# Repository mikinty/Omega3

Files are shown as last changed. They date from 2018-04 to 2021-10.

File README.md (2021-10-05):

# Omega<sup>3</sup>

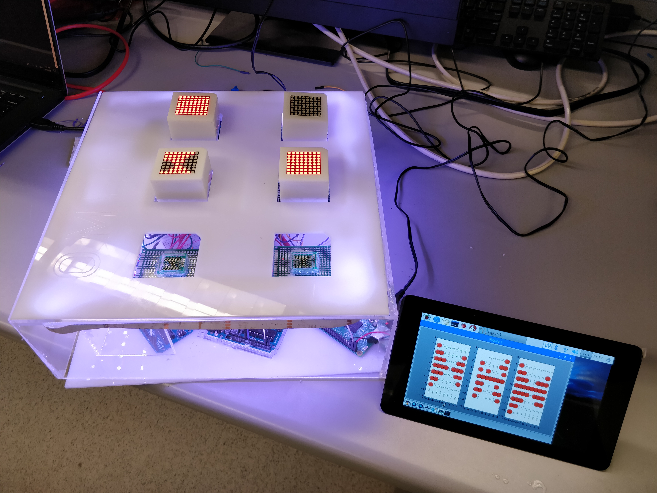
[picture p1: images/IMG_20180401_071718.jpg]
Omega3 Picture


A real-time visualization of neural networks to uncover their inner workings and help educate people about machine learning.

See the full paper at https://ieeexplore.ieee.org/document/8882046

## Directory Structure

- `CAD files/`: the CAD files used in the fabrication of Omega<sup>3</sup>.
- `images/`: pictures taken during the construction of Omega<sup>3</sup>.
- `paper/`: files used to write the paper "Real-Time Visualization of Neural Network Training to Supplement Machine Learning Education"
- `src/`: source code for the project. Includes code for the Raspberry Pi and Arduino.

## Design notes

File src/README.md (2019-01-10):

# Omega<sup>3</sup> Source Code

This directory contains the source code used to implement Omega<sup>3</sup>.
Here, we have files that test and implement the Raspberry Pi to Arduino communication interface.
The idea is that we have a Raspberry Pi that runs the neural network training code, and then sends data to the Arduino, which then displays the information on the LED matrix peripherals.

## Hardware

- Raspberry Pi 3 Model B
- Arduino Mega R2560 (can also be implemented with two Arduino UNOs)
- 8x8 LED Matrix HT16K33

## Directory Structure

- __Raspberry Pi__
  - `neuralnet.py`: the Raspberry Pi code that implements the neural network. The program takes in user input, communicates to the Arduino to display information on the LED matrices, and also plots input/output data in live-time.
  - `targetFuncs.py`: library that contains test functions to train the neural network on.
- __Arduino__
  - `testConnection`: a minimal implementation of detecting LED backpacks via hard-wired I2C addressing and displaying static information.
  - `testMatrix`: interface between the Raspberry Pi and the LED matrices. Essentially translates Rasberry Pi neural network data into images to be shown on the LED matrices.

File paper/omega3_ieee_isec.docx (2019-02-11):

# Real-Time Visualization of Neural Network Training to Supplement Machine Learning Education

Michael You and Jessica Yin

Carnegie Mellon University, myou, jessicay@andrew.cmu.edu

Abstract - In machine learning, neural networks have excelled at performing tasks at a high level with a simple and flexible implementation. Neural networks are particularly well-suited for novice programmers due to the availability of open-source libraries like TensorFlow and Caffe. However, novice programmers often neglect to learn beyond the black-box behaviors that these libraries provide. Introductory college students often lack the understanding of neural network internals, such as hidden layers and activation functions, and their interactions during training, which are crucial to efficiently solving more complex problems. Here, we present Omega³, a device that opens up the black-box of neural networks by visually representing how hidden layers behave during training in real-time. In addition, Omega³ provides an engaging tactile and visual educational experience to students, and waives the requirement for a strong programming background in order to learn about neural networks. In this paper, we will discuss the fabrication and set-up of Omega³ as well as evaluate and compare Omega³ to traditional lecture-based learning.

Index Terms – Hidden layer, modular, neural networks, visualization

Introduction

In the past decade, machine learning has emerged as one of the dominant techniques in software for building solutions in autonomous driving, natural language processing, image processing, and many other domains [1, 2, 3]. One leading technique for machine learning models is the neural network (NN), which is usually the best performing model compared to others [4, 5, 6, 7]. However, despite their success, the inner workings of NNs are seldom understood due to the sophisticated math associated with how they work [8]. As a result, people often treat NNs as black-boxes, which can lead to blindly changing parameters and features that describe the NN. As NNs become more complex, understanding how they work is vital for them to be used properly and effectively in future applications.

Currently, NN visualizations are limited. They are primarily software based, and require some degree of machine learning, data science, and/or programming experience [9, 10, 11].

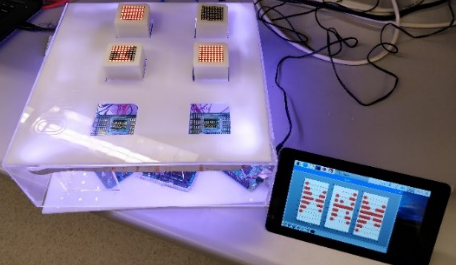
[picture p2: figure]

# Figure I

omega³ performing real-time training.

As machine learning gains popularity, an increasing number of people will need to learn about models such as neural networks. However, the programming and math can be inaccessible, out of scope, and present a high overhead to both students and teachers alike to learn.

There are numerous educational tools that target an analogous challenge with teaching children the fundamentals of programming. For example, toys such as Fisher-Price Think & Learn Code-a-pillar, littleBits, and LEGO BOOST make abstract programming concepts accessible to preschool and elementary school aged children [12, 13, 14]. These toys rely on hands-on and modular features to be engaging and effective, appealing to both visual and physical learning pathways.

TensorFlow Playground, a web-based interactive NN visualization, has been developed to address the growing need for accessible NN education. However, it still requires an extensive background in programming and math for basic use and may be less advantageous for tactile learners.

Building upon TensorFlow Playground, we present a simple, modular, physical representation of a NN that is easily accessible and requires minimal technical experience. This device, which we call Omega³, has customizable data and training settings, and displays a real-time visual of how a NN works as it runs. The user can move modular neuron blocks on the device that change the structure of the NN in real-time, which gives interactive feedback of the relationship between NN structure and model accuracy. This paper will first describe the materials of Omega³, the construction, the code, a few sample runs demonstrating features of Omega³, and finally, a method for evaluating its effectiveness.

Fabrication

I. Materials and Overview

The component names and the current (as of December 2018) prices of the required materials are listed in Table I, and the product links are provided in Appendix A. The equipment required for the assembly of the device is listed in Table II. All items are initial investments and the device can be reused numerous times once assembled.

Because the fabrication process mostly consists of assembling components, the device can be put together by either the supervisors of the workshop or the students.

TABLE I

Materials

Qty | Item | Price
1 1 3 6 6 42 66 3 1 | Raspberry Pi Elegoo Mega 2560 Microcontroller Acrylic Sheets, 24” x 12” x 1/8” LED Matrix, 8x8, with HT16K33 Module Protoboard Pogo pins Socket pins IRF644 MOSFET (optional) LED Strip (optional) Total: | $35.00 $13.99 $8.99 each $13.99, 3-pack $6.95, 10-pack $7.99, 100-pack $8.30, 50-pack $1.50 each $8.49 $127.18

TABLE II

Equipment Required for Fabrication

Item

Laser Cutter

HDMI Display (e.g. computer monitor or Raspberry Pi display)

Soldering Iron with Solder

Hot Glue Gun

II. Step-by-Step Fabrication Process of Neuron Blocks

The main display components of Omega³ are the neuron blocks, which display the decision boundary of each hidden layer. Each block consists of:

- An 8x8 LED matrix display with the HT16K33 module
- An acrylic enclosure
- Protoboard
- Socket pins (11)

The assembly process for the neuron blocks is illustrated in Figure II. Source files for laser-cut parts can be found in Appendix B.

1. Laser cut the acrylic components with patterns provided in Appendix B.
2. Cut protoboard to size and solder socket pins to protoboard in configuration shown in Fig. II-A.
3. Wire LED matrix to socket pins and protoboard according to Fig. II-B. The completed step is show in Fig. II-C.
4. Apply adhesive and press together the acrylic components, protoboard, and LED matrix to complete the assembly of the neuron block. An exploded view is provided in Fig. II-D (wires not shown) [15]. Fig. II-E shows the completed neuron blocks.

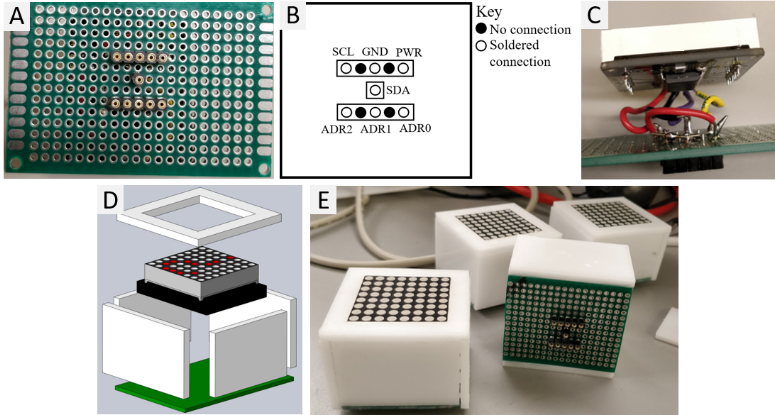
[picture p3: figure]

# Figure II

Illustrated step-by-step fabrication process of neuron blocks.

III. Step-by-Step Fabrication Process of Base

The base of the device, where users place neuron blocks, hosts landing pads and socket pins that allow the neuron blocks to be connected to the microcontroller and the Raspberry Pi. An LED strip was glued around the perimeter of the inside of the base, purely for decoration, and thus is optional. The base consists of:

- An acrylic enclosure
- Protoboards (6)
- Pogo pins (42)
- Microcontroller
- Raspberry Pi
- LED strip & IRF644 MOSFETs (optional)

The assembly process for the base is illustrated in Figure III. Source files for laser-cut parts can be found in Appendix B.

1. Laser cut acrylic components with patterns provided in Appendix B.
2. Solder the pogo pins to the protoboard as shown in Fig. III-A.
3. Solder a wire to one end of each pogo pin and connect the wire to the appropriate pin of the microcontroller. The completed step is shown in Fig. III-B. Fig. III-C shows how the LED matrix display and the socket pins of the neuron block fit onto the pogo pins.
4. Wire the microcontroller and Raspberry Pi according to Fig. III-D.
5. Assemble the base by applying adhesive to the acrylic components and the protoboards. Acrylic supports may be placed between the layers for additional stability if desired. Place the Raspberry Pi and microcontroller inside the base before completing the assembly. An exploded view of the assembly can be found in Fig. III-E (wires not shown) [16, 17].
6. Connect the HDMI display to the Raspberry Pi.
7. Adhere the LED strip to the perimeter of the base. (Optional) Fig. III-F shows the completed base after this step.

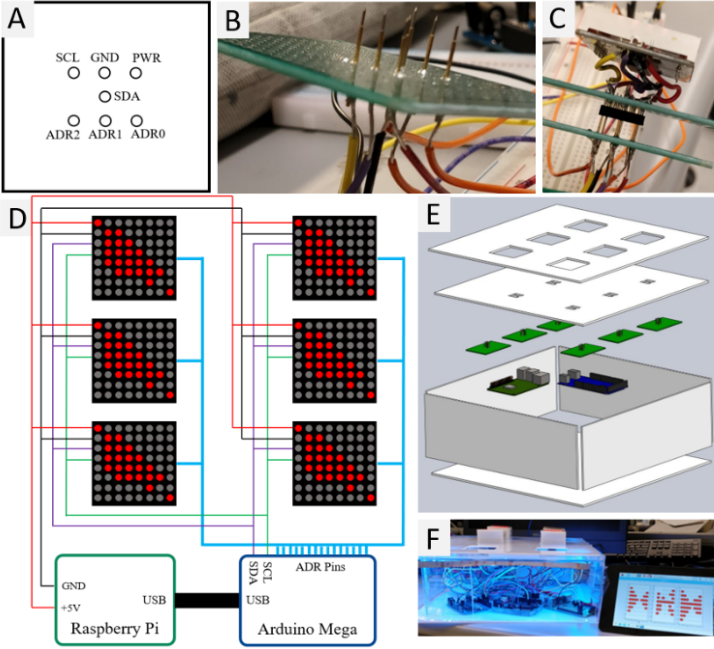
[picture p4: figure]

# Figure III

Illustrated step-by-step fabrication process of base.

# Software

The Raspberry Pi and microcontroller were used to interpret user input, train the neural network, and provide real-time feedback of neural network training on the LED matrices. The Raspberry Pi was programmed to simultaneously train the neural network and relay the hidden layer data to the microcontroller. The microcontroller was programmed to interpret the serial communication from the Raspberry Pi and display it on the LED matrixes of connected neuron blocks. The complete code for the microcontroller and the Raspberry Pi can be found in Appendix B. The Raspberry Pi runs Raspbian and PyBrain, for which the weblinks and installation instructions are included in Appendix B.

I. Raspberry Pi Software

The software on the Raspberry Pi has the following workflow:

1. User chooses the type of data for NN to be trained on (e.g., solid, checkerboard, cross, kite, etc.).
2. Program randomly samples from chosen data distribution.
3. Program begins training the NN, sending hidden layer data to the microcontroller after each epoch.

During the entire training process, the Raspberry Pi will display the original data set, the sampled data set, and the predicted data set via the HDMI display. Figure IV shows an example of what would be shown on the HDMI display.

# Figure IV

An example of hdmi output from the raspberry pi. graphs left to right: original data set, sampled data set, predicted data set.

II. Microcontroller Software

The software on the microcontroller has the following structure:

1. Read LED matrix addresses.
2. Initialize LED matrix objects.
3. While the LED matrix is connected:
  a. Read from serial port.
  b. Interpret message.
  c. Display information to LED matrix.

The open source Arduino IDE was used to program the Elegoo Mega 2560 with the Omega³ software. The LED Matrix library from Adafruit will need to be installed before use of the Omega³ Arduino program. The weblinks and installation instructions for the Arduino IDE and the Adafruit LED Matrix Library can be found in Appendix B.

# Evaluating Effectiveness

To evaluate the effectiveness of Omega³ as an educational device, the following experiment will be conducted. A pool of 24 students from Carnegie Mellon University, aged 18-22 years old, will be selected to participate based on their backgrounds with machine learning. One third of the students will have no previous exposure to neural networks, another third will have had some exposure to neural networks, and finally the last third will be proficient with neural networks. Half of each student group, categorized by their previous experience with neural networks, will be given a presentation about neural networks, while the other half will be given time to use Omega³.

Each user trial will be conducted with students individually. The trial will consist of the following steps:

1. Take the pre-activity survey about NN knowledge.
2. Participate in one 30-minute activity of:
  a. Learn about neural networks through presentation slides and an oral presentation, or
  b. Learn about neural networks through interaction with Omega³ and an oral presentation.
3. Take the first post-activity survey about NN knowledge immediately after the conclusion of the activity.
4. Approximately one week later, take the second post-activity survey.

The pre-activity survey will consist of the following questions:

1. Rate your overall understanding of neural networks on a scale of 1-10.
2. Explain how a neural network operates in your own words.

The first post-activity survey will include questions 1-2 from the pre-activity survey as well as the following:

3. Rate how useful your activity was to learning about neural networks on a scale of 1-10 (post-activity only).
4. Please suggest improvements to the device if any of its features were unclear or difficult to use (post-activity for 2b only).

The second post-activity survey will consist of questions 1-3 from the pre-activity and first post-activity surveys.

Once the experiment is completed, the results will be collected, analyzed, and reported.

# Conclusion

Omega³ is a novel visual and interactive approach to neural network education. The device’s modular nature and hands-on interface may be useful to a wide range of students with varying levels of experience with math, programming, and machine learning. Omega³ will increase accessibility to the understanding of how NNs operate as they become more widely utilized in everyday applications.

For future work, we will first execute the study on effectiveness presented in the paper. After analyzing the collected data, we will be able to identify improvements for future iterations of the device. A prospective feature is an expanded data functionality of Omega³ so that users can select from different types of data sets rather than the current binary sets included in the program, to display more capabilities of neural networks. This device could also be tested for effectiveness and use with a wider audience, such as high school and middle school students. We hope the development of Omega³ will emphasize a hands-on and interactive nature in STEM education.

# Acknowledgement

We would like to thank HackPrinceton for giving us the resources to build Omega³ and the 1517 Fund for providing financial support for the continued development of Omega³. We would also like to thank Professor Carmel Majidi and Tess Hellebrekers for useful suggestions to the manuscript.

# References

[1] Mitchell, Tom M. Machine Learning. McGraw-Hill, 1997.

[2] Bridge, James P., Holden, Sean B. and Paulson, Lawrence C, “Machine learning for first-order theorem proving,”Journal of Automated Reasoning, vol. 53,pp. 141–172, Aug 2014.

[3] Sarikaya, Ruhi, Hinton, Geoffrey E. and Deoras, Anoop. “Application of deep belief networks for natural language understanding,” IEEE/ACM Trans. Audio, Speech and Lang. Proc., vol. 22, pp. 778–784, Apr. 2014.

[4] Ciregan, Dan, Meier, Ueli and Schmidhuber, Juergen. “Multi-column deep neural networks for image classification,” in 2012 IEEE Conference on Computer Vision and Pattern Recognition, pp. 3642–3649, June 2012.

[5] Krizhevsky, Alex, Sutskever, Ilya and Hinton, Geoffrey E. “Imagenet classification with deep convolutional neural networks,”Commun. ACM, vol. 60,pp. 84–90, May 2017.

[6] Wieczorek, Szymon, Filipiak, Dominik and Filipowska, Agata. “Semantic image-based profiling of users’ interests with neural networks,” 10 2018.

[7] X. Li and X. Wu, “Constructing long short-term memory based deep re-current neural networks for large vocabulary speech recognition,”CoRR,vol. abs/1410.4281, 2014.

[8] Olah, Christopher. “Neural networks, manifolds, and topology.”https://colah.github.io/posts/2014-03-NN-Manifolds-Topology/. Accessed: 2018-12-24.

[9] Tensorflow, “A neural network playground.” http://playground.tensorflow.org/. Accessed: 2018-12-24.

[10] Yosinski, Jason, Clune, Jeff, Nguyen, Anh, et al. “Understand-ing neural networks through deep visualization.” http://yosinski.com/deepvis. Accessed: 2018-12-24.

[11] Bolton, Kris. “A practical introduction to artificial neural networkswithpython.” http://krisbolton.com/a-practical-introduction-to-artificial-neural-networks-with-python/. Accessed: 2018-12-24.

[12] “Think & Learn Code-a-pillar”. https://fisher-price.mattel.com/shop/en-us/fp/think-learn/think-learn-code-a-pillar-dkt39. Web. Accessed: January 14, 2019.

[13] “littleBits”. https://littlebits.com/. Web. Accessed: January 14, 2019.

[14] “LEGO BOOST”. https://www.lego.com/en-us/themes/boost. Web. Accessed: January 14, 2019.

[15] Sami, Mohamed. "LED Matrix 8*8." https://grabcad.com/library/led-matrix-8-8. Web. Accessed: December 25, 2018.

[16] Stoianovici, Dan. "Raspberry Pi 3B+ Mock." https://grabcad.com/library/raspberry-pi-3b-mock-1. Web. Accessed: December 25, 2018.

[17] hannah_mii. "Arduino Mega." https://grabcad.com/library/arduino-mega-6. Web. Accessed: December 25, 2018.

# Author Information

Michael You, Undergraduate student, Department of Electrical and Computer Engineering, Carnegie Mellon University.

Jessica Yin, Undergraduate student, Department of Mechanical Engineering, Carnegie Mellon University.

# Appendix A - Materials

Web links to the products used to fabricate Omega³ are listed below:

- Raspberry Pi: https://www.adafruit.com/product/3775?src=raspberrypi
- Elegoo Mega 2560: http://a.co/d/0fUEueU
- Acrylic sheets: http://a.co/d/bpR7mZL
- LED matrix display: http://a.co/d/isXfqF9
- Protoboards: http://a.co/d/e8fosrh
- Pogo pins: http://a.co/d/5AjGkkk
- Socket pins: https://www.digikey.com/short/pc5zvq
- IRF644 MOSFET: https://goo.gl/NhZn2W
- LED Strip: http://a.co/d/isZLFzB

# Appendix B - Source Files

Web links to various source files are listed below:

- Patterns for the laser cutting, code for the Raspberry Pi, and code for the microcontroller can be found here: https://github.com/mikinty/Omega3
- Raspberry Pi New Out Of the Box Software Installer (NOOBS) for Raspbian: https://www.raspberrypi.org/downloads/noobs/
- PyBrain, machine learning library for Python: http://pybrain.org/
- Arduino IDE: https://www.arduino.cc/en/main/software
- Adafruit LED Matrix library: https://github.com/adafruit/Adafruit_LED_Backpack

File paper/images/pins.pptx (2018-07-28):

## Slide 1

SCL

GND

PWR

SDA

ADR2

ADR1

ADR0

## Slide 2

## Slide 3

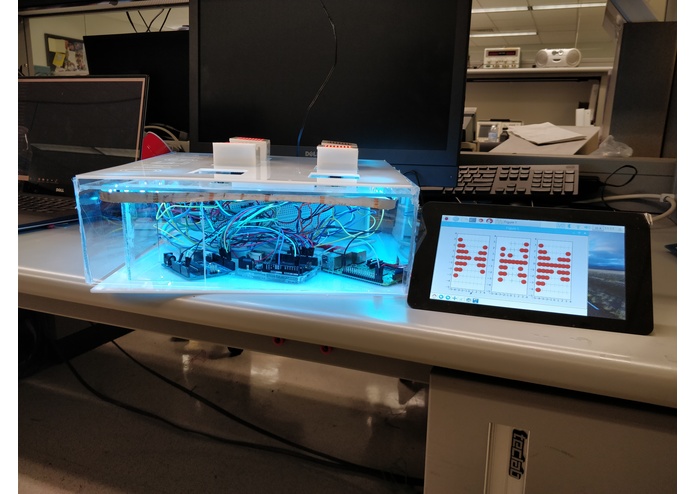
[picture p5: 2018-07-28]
paper/images/sideView.jpg

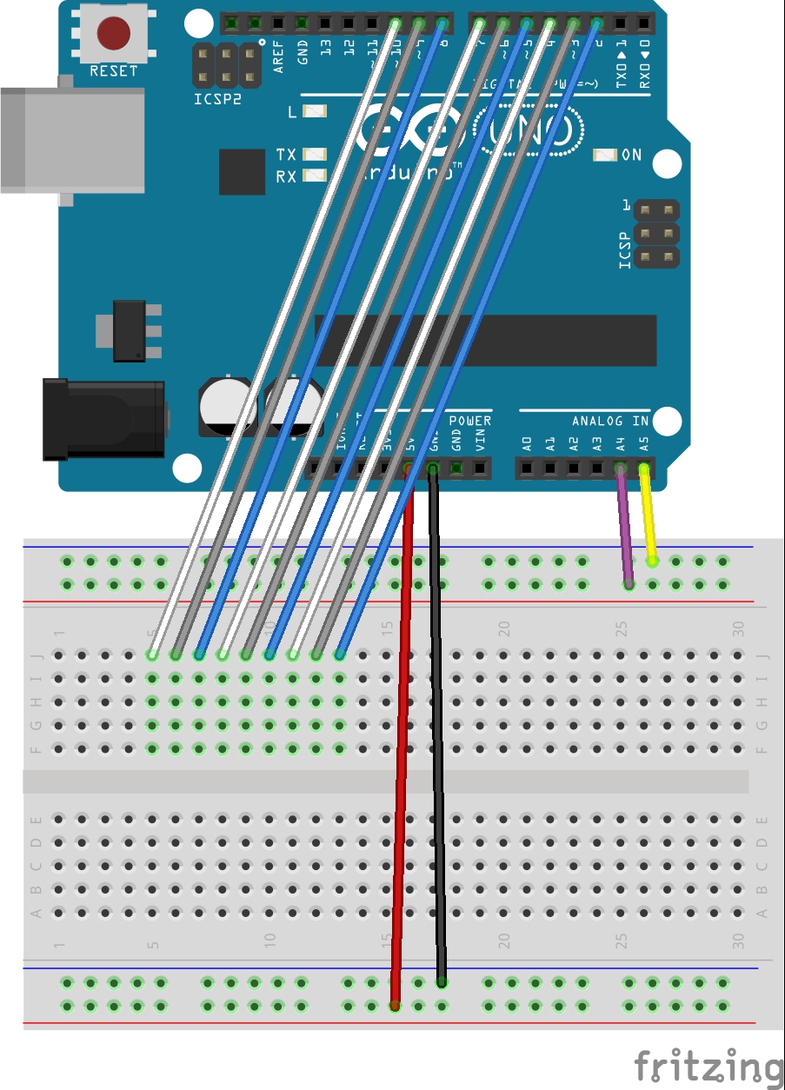
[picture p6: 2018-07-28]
paper/images/adr_bb.jpg

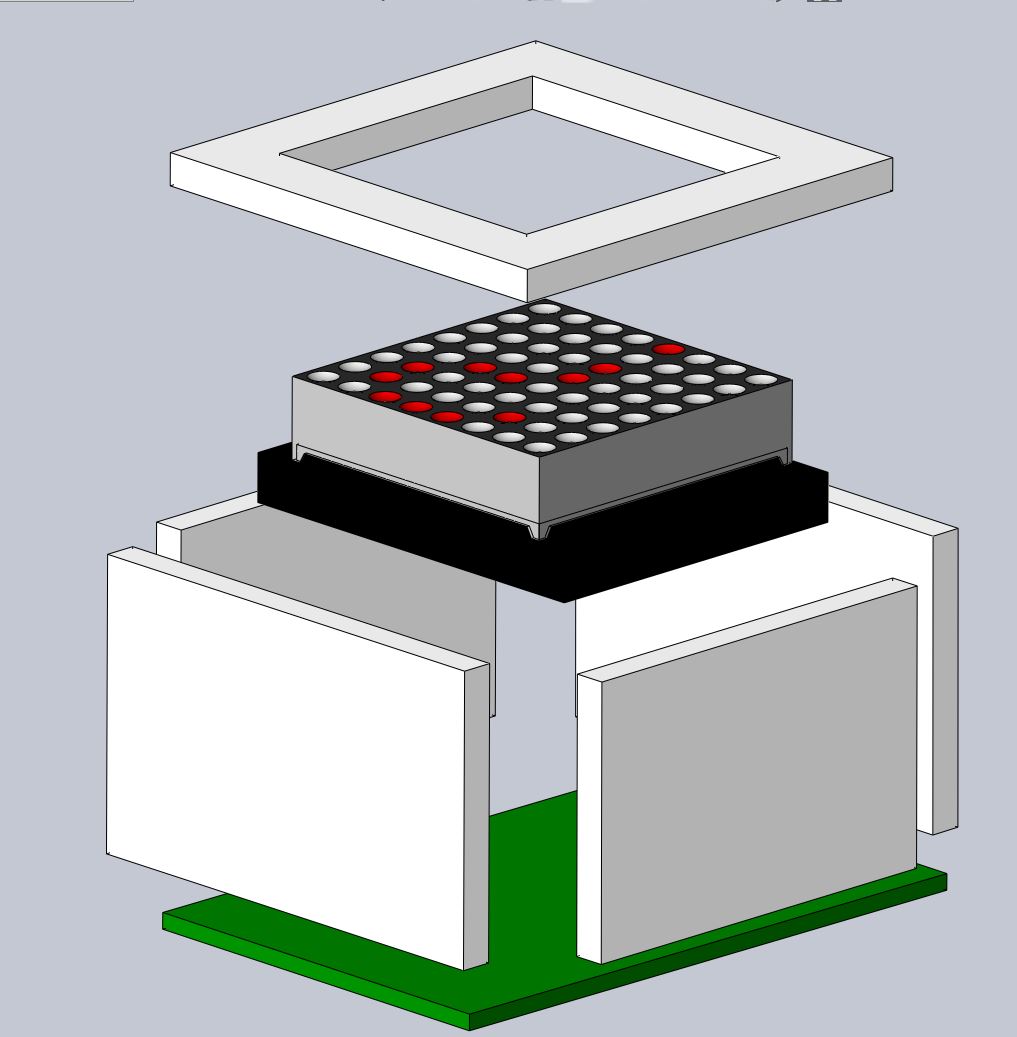
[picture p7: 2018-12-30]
paper/images/neuronblock_exploded.JPG

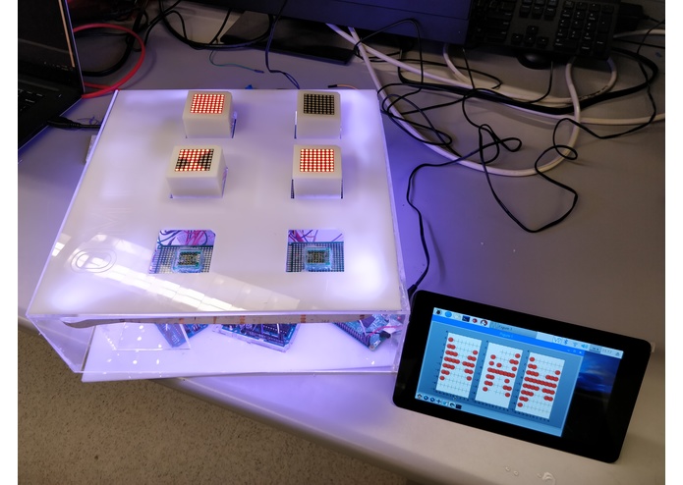
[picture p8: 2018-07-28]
paper/images/main.jpg

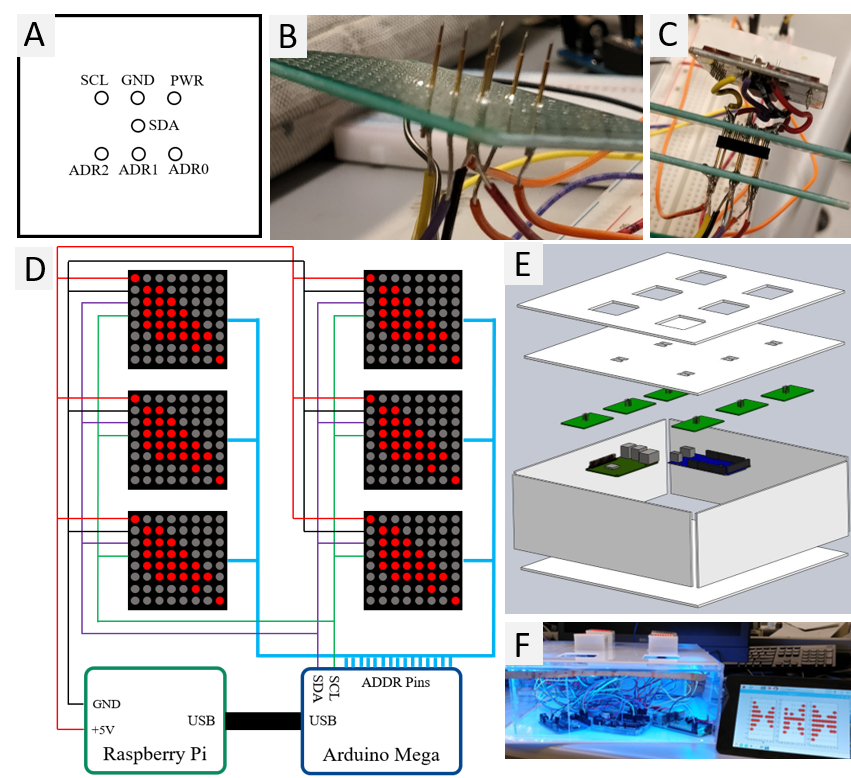
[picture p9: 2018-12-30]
paper/images/fig3v6.png

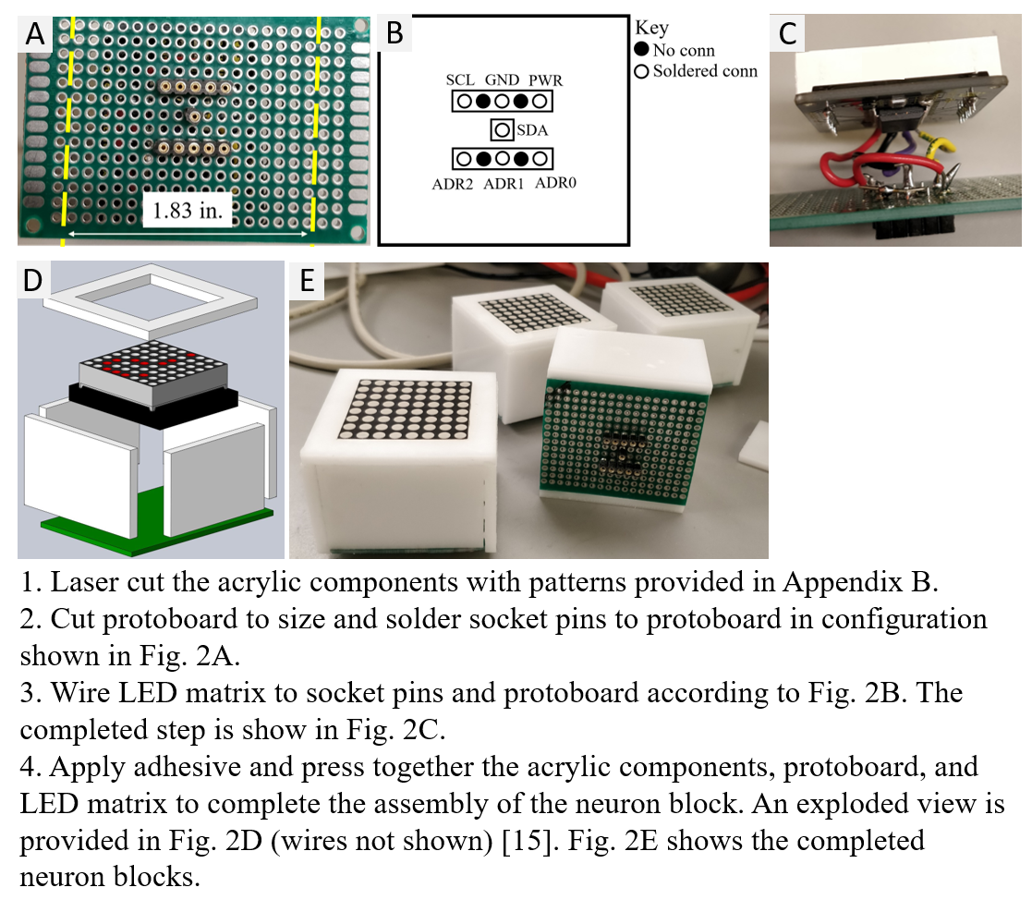
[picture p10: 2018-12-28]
paper/images/group1.png

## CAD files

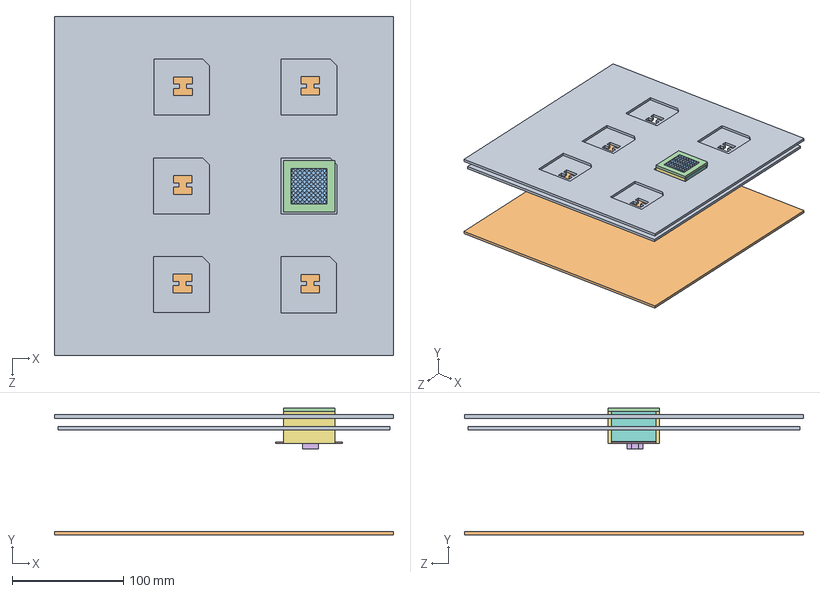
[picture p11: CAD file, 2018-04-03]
CAD files/omega3.SLDASM
304.8 x 113.8 x 304.8 mm
topboard
LEDbackpack
LED Matrix
cubetop
protoboard
cubebottompins
cubeside1 x 2
cubeside2 x 2
middleboard
base

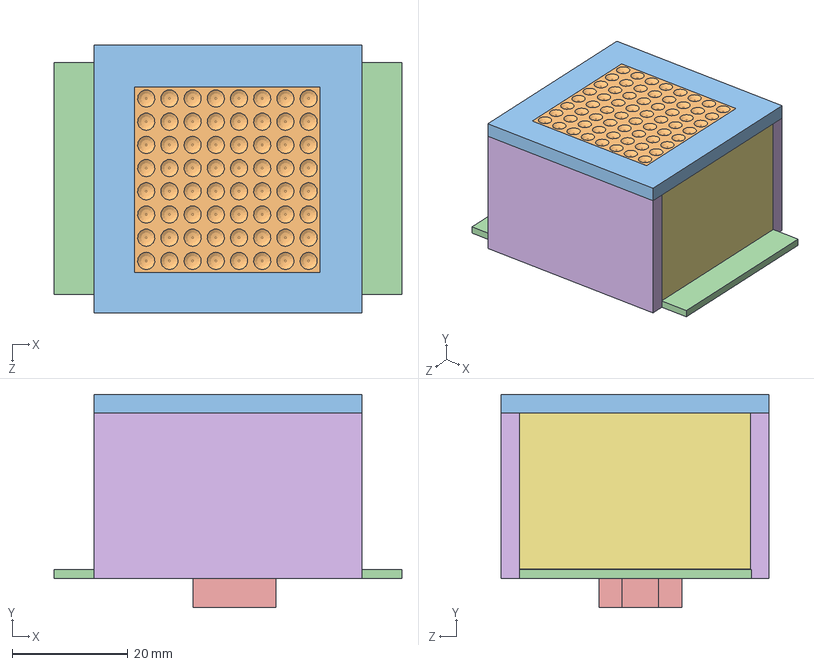
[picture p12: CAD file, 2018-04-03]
CAD files/cube.SLDASM
60.0 x 36.8 x 46.2 mm
LEDbackpack
LED Matrix
cubetop
protoboard
cubebottompins
cubeside1 x 2
cubeside2 x 2

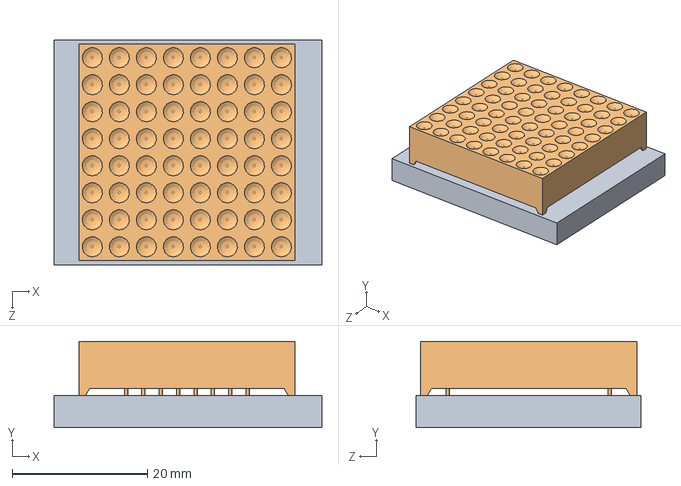
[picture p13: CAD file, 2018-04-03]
CAD files/ledmatrixbackpack.SLDASM
39.7 x 12.8 x 33.3 mm
LEDbackpack
LED Matrix

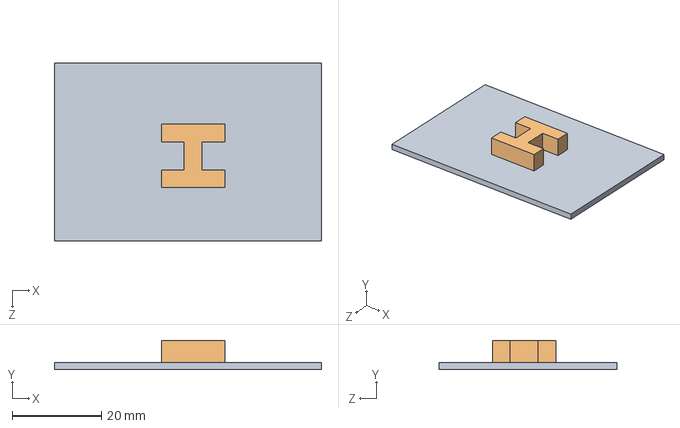
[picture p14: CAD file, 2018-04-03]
CAD files/cubebottom.SLDASM
60.0 x 6.59 x 40.0 mm
protoboard
cubebottompins

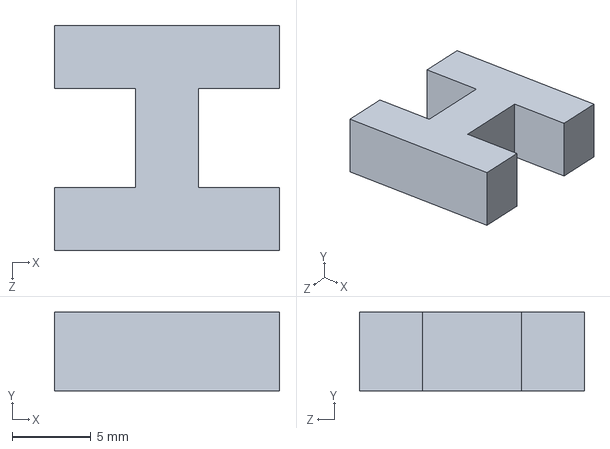
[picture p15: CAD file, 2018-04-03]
CAD files/cubebottompins.SLDPRT
14.3 x 5.00 x 14.3 mm

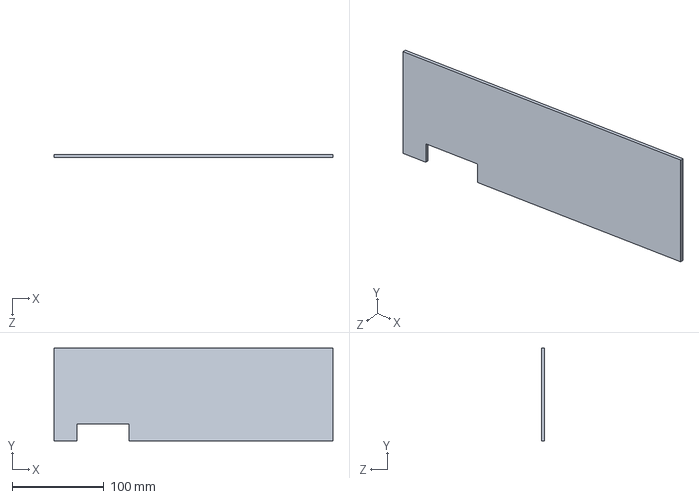
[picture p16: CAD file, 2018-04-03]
CAD files/side2.SLDPRT
304.8 x 101.6 x 3.17 mm

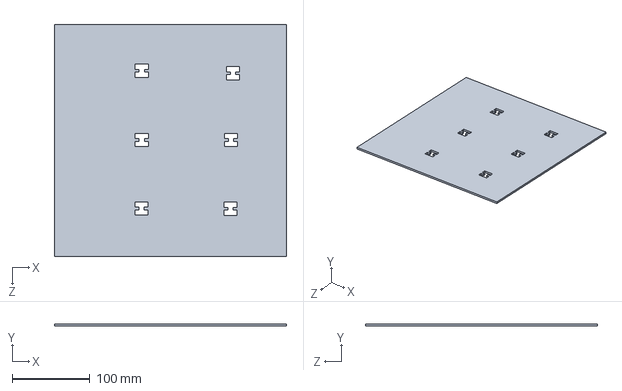
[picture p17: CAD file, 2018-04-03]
CAD files/middleboard.SLDPRT
298.4 x 3.17 x 298.4 mm

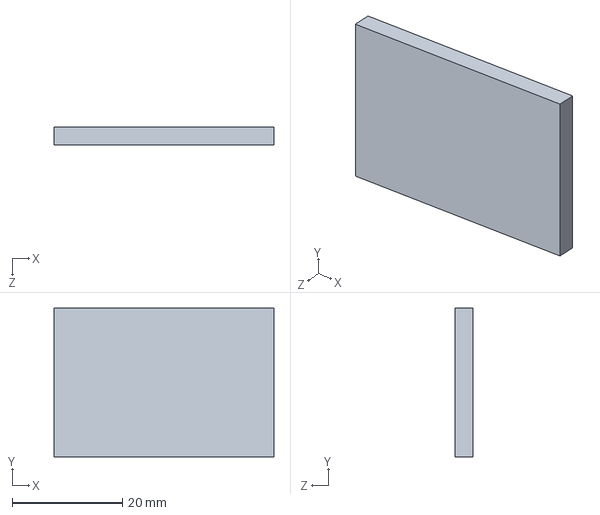
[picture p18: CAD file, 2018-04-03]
CAD files/cubeside2.SLDPRT
39.9 x 26.9 x 3.17 mm

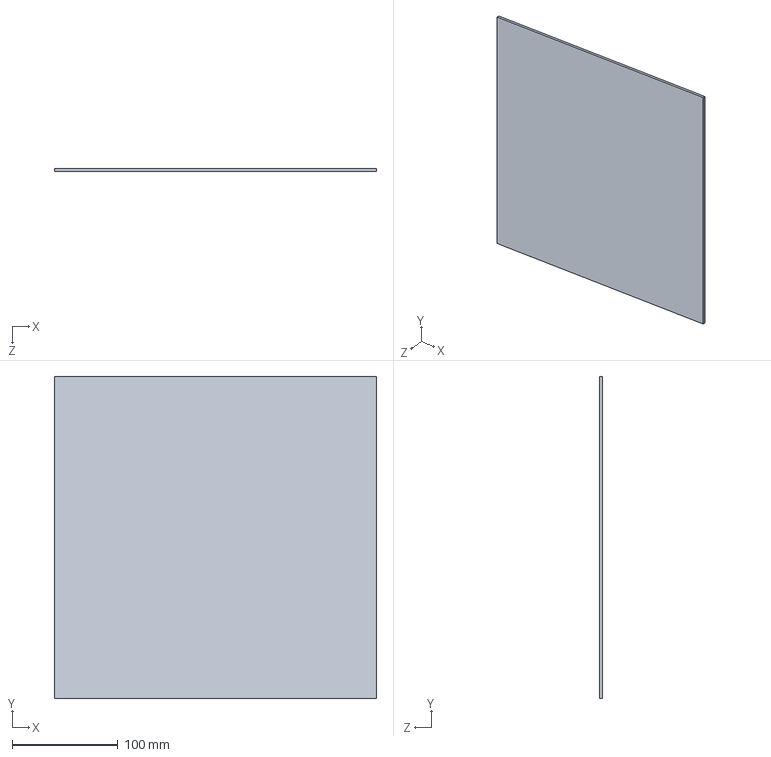
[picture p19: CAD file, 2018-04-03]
CAD files/base.SLDPRT
304.8 x 304.8 x 3.17 mm

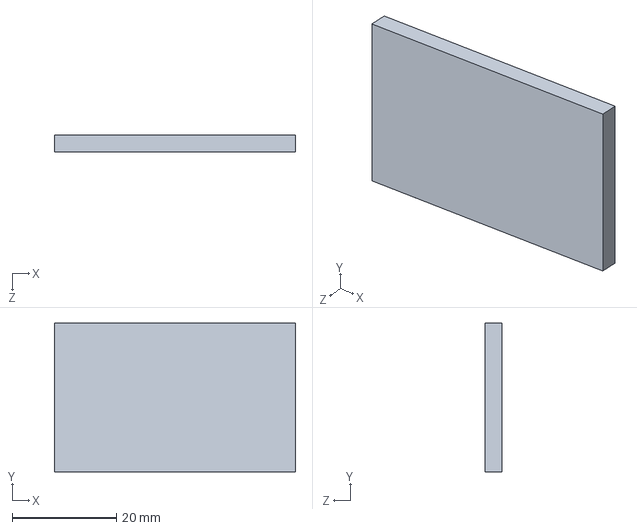
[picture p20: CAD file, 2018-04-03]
CAD files/cubeside1.SLDPRT
46.2 x 28.6 x 3.17 mm

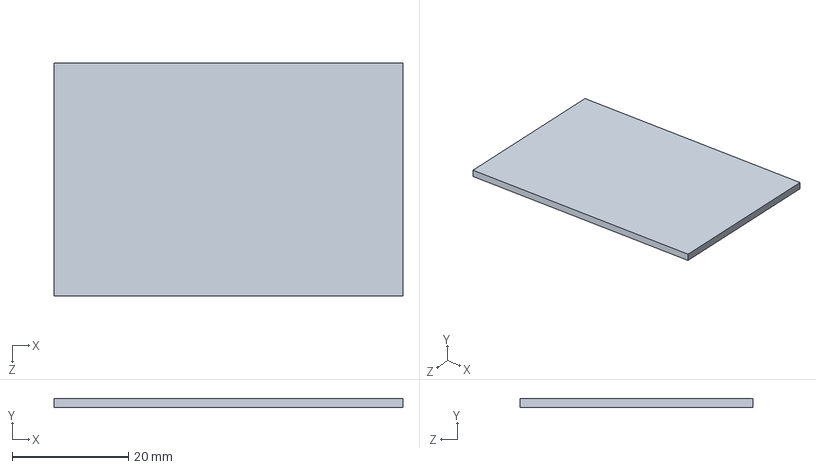
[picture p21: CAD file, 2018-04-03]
CAD files/protoboard.SLDPRT
60.0 x 1.59 x 40.0 mm

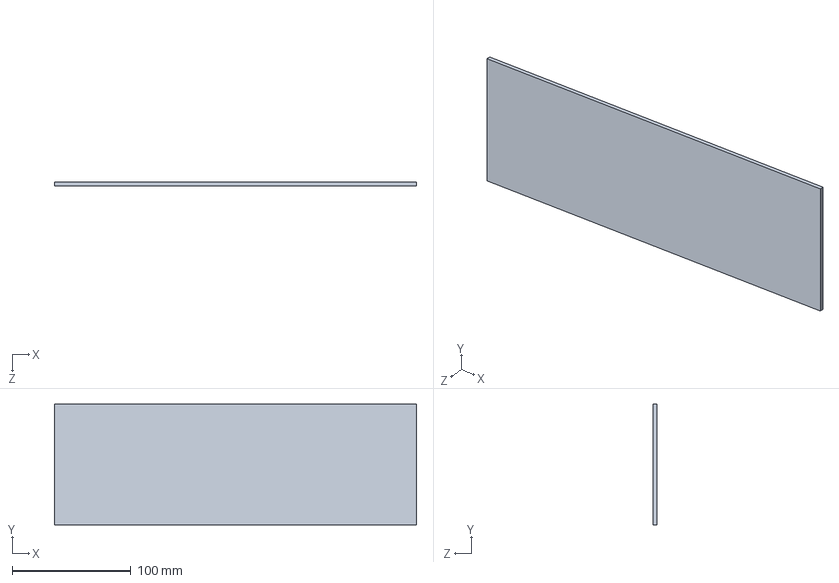
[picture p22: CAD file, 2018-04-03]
CAD files/side1.SLDPRT
304.8 x 101.6 x 3.17 mm

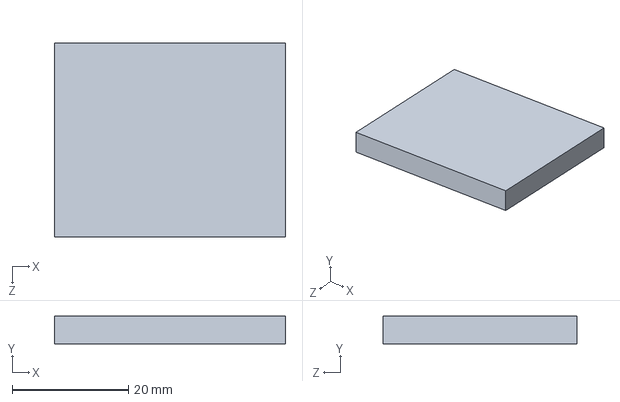
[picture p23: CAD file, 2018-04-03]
CAD files/LEDbackpack.SLDPRT
39.7 x 4.76 x 33.3 mm

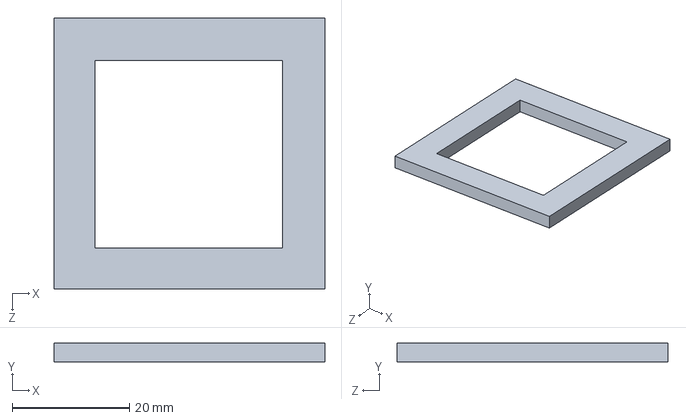
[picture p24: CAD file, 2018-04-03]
CAD files/cubetop.SLDPRT
46.2 x 3.17 x 46.2 mm

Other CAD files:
CAD files/middlesupports.SLDPRT
CAD files/topboard.SLDPRT

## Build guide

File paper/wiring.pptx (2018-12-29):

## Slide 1

Raspberry Pi

SDA

SCL

ADDR Pins

Arduino Mega

+5V

GND

USB

USB

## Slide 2

- https://upload.wikimedia.org/wikipedia/commons/thumb/9/97/Raspberry_Pi_3_B%2B_%2839906369025%29.png/1200px-Raspberry_Pi_3_B%2B_%2839906369025%29.png

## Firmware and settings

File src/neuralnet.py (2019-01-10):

'''
Implementation of the neural network that is run on the Raspberry Pi 
and sent to the Arduino for display on Omega3. 

We use the pybrain library to make our neural network much 
easier to implement, and to use for gaining hidden layer data.

This program also plots in livetime the reference, input and output
data points, to give the user an idea of what progress the neural network
has in its training.

TODO: port constants into a CONSTANTS.py file.

NOTE: this program is currently implemented for two Arduino UNOs. 
      A future version of this program will only use one Arduino Mega.
'''
import random
import math
import time
import serial
import serial.tools.list_ports

# target functions
import targetFuncs

# pybrain imports
from pybrain.structure import FeedForwardNetwork
from pybrain.tools.shortcuts import buildNetwork  # network
from pybrain.datasets import SupervisedDataSet  # dataset
from pybrain.supervised.trainers import BackpropTrainer # training alg
from pybrain.structure import LinearLayer, SigmoidLayer
from pybrain.structure import FullConnection

# plotting library
import numpy as np
import matplotlib.pyplot as plt

# hook up arduino to serial port
ports = list(serial.tools.list_ports.comports())

# Arduino serial numbers for detection
hidden2Serial = '55333303934351915152'
hidden1Serial = '855393139313517121F1'

print(ports)
arduinoS1 = [p[0] for p in ports if (hidden1Serial in p[2])]
arduinoS2 = [p[0] for p in ports if (hidden2Serial in p[2])]

# print(arduinoS1, arduinoS2)

ard1 = serial.Serial(arduinoS1[0], timeout=0)
ard2 = serial.Serial(arduinoS2[0], timeout=0)

# Type of NN we are using
net = FeedForwardNetwork()
netOne = FeedForwardNetwork()

# parameters
numEpochs = 300
learningRate = 10
numFeatures = 7
numTrain = 100 # amount of training data
numHiddenUnits1 = 3
numHiddenUnits2 = 3
(xMin, xMax, yMin, yMax) = (-4, 4, -4, 4) # dim. of LED matrix
displayRate = 0.2 # period of display time

def sigmoid(x):
    return 1 / (1 + math.exp(-x))


def sendMatrix(m, layer, matrixNum):
    '''
    function for sending data to matrix

    :param m: 8x8 bit matrix
    :param layer: which hidden layer to send info to
    :param matrixNum: which matrix to communicate to
    '''
    arduino = ard1 # default

    # choose the arduino based on layer
    if layer == 2:
        arduino = ard2

    arduino.write(b's') # signal start

    arduino.write(str(matrixNum).encode()) # indicate which neuron

    # send over data for matrix display
    for i in m:
        for j in i:
            arduino.write(str(j).encode())


def pesos_conexiones(n):
    '''
    Prints out hidden layer data from a neural network.

    :param n: pybrain neural network
    '''
    paramArr = {}
    for mod in n.modules:
        for conn in n.connections[mod]:
            temp = []
            for cc in range(len(conn.params)):
                temp.append(conn.params[cc])

                if len(temp) == 21:
                    paramArr['h1'] = temp
                elif len(temp) == 9:
                    paramArr['h2'] = temp

    return paramArr


def generateData(N, funNumber):
    '''
    Generate bit data on 8x8 for the neural network to train on.

    :param N: number of training data points to give to the model
    :param funNumber: function number label
    '''
    inputArr = []
    outputArr = []

    # create our input data
    for x in range(N):
        # generate random values
        xVal = random.uniform(xMin, xMax)
        yVal = random.uniform(yMin, yMax)

        # NN input data with features
        inputArr.append([xVal, yVal, xVal*xVal, yVal*yVal, xVal*yVal, math.sin(xVal), math.sin(yVal)])

        # Choose function
        lib = {
            0: targetFuncs.yGeZero,
            1: targetFuncs.xGeZero,
            2: targetFuncs.checkerboard,
            3: targetFuncs.circle,
            4: targetFuncs.diag,
            5: targetFuncs.chess,
            6: targetFuncs.corners,
            7: targetFuncs.kite
        }

        # Labels for input data
        if (lib[funNumber])(xVal, yVal):
            outputArr.append([1])
        else:
            outputArr.append([0])

    print('Output DATA')
    print(outputArr)

    return inputArr, outputArr, lib[funNumber]


def setupNN(inputArr, outputArr, numFeatures, nodesH1, nodesH2):
    # Globals
    global in_to_hidden
    global hidden_to_hidden2
    global hidden2_to_out

    # Create NN layers. Numbers indicate dimension = number of nodes in layer
    inLayer = LinearLayer(numFeatures)
    hiddenLayer = SigmoidLayer(nodesH1)
    hiddenLayer2 = SigmoidLayer(nodesH2)
    outLayer = LinearLayer(1)

    # Add NN components
    net.addInputModule(inLayer)
    net.addModule(hiddenLayer)
    net.addModule(hiddenLayer2)
    net.addOutputModule(outLayer)

    # Make neural network connections
    in_to_hidden = FullConnection(inLayer, hiddenLayer)
    hidden_to_hidden2 = FullConnection(hiddenLayer, hiddenLayer2)
    hidden2_to_out = FullConnection(hiddenLayer2, outLayer)


    net.addConnection(in_to_hidden)
    net.addConnection(hidden_to_hidden2) # lazy full connection
    net.addConnection(hidden2_to_out)

    # Don't delete this
    net.sorted = False
    net.sortModules() # random command to make this work

    # add dataset to the NN
    ds = SupervisedDataSet(7,1)

    for i,j in zip(inputArr, outputArr):
        ds.addSample(tuple(i),(tuple(j)))

    # training algorithm
    m1 = BackpropTrainer(net, ds)

    return m1


def trainNN(model, numEpochs):
    for epoch in range(numEpochs):
        # Give time for the LED Matrix to show things
        print('epoch', epoch)
        time.sleep(displayRate)
        params = pesos_conexiones(net)

        # TRAIN NN and report error
        model.trainEpochs(learningRate)
        print('Model train error:', model.train()) #error

        # parse params
        h1Params = params['h1']
        inToH1 = h1Params[0:7]
        inToH2 = h1Params[7:14]
        inToH3 = h1Params[14:]

        h2Params = params['h2']
        hToH1 = h2Params[0:3]
        hToH2 = h2Params[3:6]
        hToH3 = h2Params[6:]

        # for plotting
        xRefPos = []
        xRefNeg = []
        yRefPos = []
        yRefNeg = []

        ### Print to LED Matrix ###
        # print('Output Layer:')
        outputMatrix = []
        hOne1 = []
        hOne2 = []
        hOne3 = []

        hTwo1 = []
        hTwo2 = []
        hTwo3 = []

        # Compute the node values
        for x in range(-4, 4):
            outputList = []
            hO1 = []
            hO2 = []
            hO3 = []

            hT1 = []
            hT2 = []
            hT3 = []

            for y in range(-4, 4):
                inArr = [x,y, x*x, y*y, x*y, math.sin(x), math.sin(y)]

            # predict with NN
            compute = net.activate(inArr)

            ## compute hidden layers ##
            bias = 0

            # hidden layer 1
            temp1 = 0 + (sigmoid(sum(i[0]*i[1] for i in zip(inArr, inToH1)) + bias) >= 0.5)
            temp2 = 0 + (sigmoid(sum(i[0]*i[1] for i in zip(inArr, inToH2)) + bias) >= 0.5)
            temp3 = 0 + (sigmoid(sum(i[0]*i[1] for i in zip(inArr, inToH3)) + bias) >= 0.5)

            hO1.append(temp1)
            hO2.append(temp2)
            hO3.append(temp3)

            hLayer1 = [temp1, temp2, temp3]

            # hidden layer 2
            temp21 = 0 + (sigmoid(sum(i[0]*i[1] for i in zip(hLayer1, hToH1)) + bias) >= 0.5)
            temp22 = 0 + (sigmoid(sum(i[0]*i[1] for i in zip(hLayer1, hToH2)) + bias) >= 0.5)
            temp23 = 0 + (sigmoid(sum(i[0]*i[1] for i in zip(hLayer1, hToH3)) + bias) >= 0.5)

            hT1.append(temp21)
            hT2.append(temp22)
            hT3.append(temp23)

            if compute >= 0.5:
                outputList.append(1)
                xRefPos.append(x)
                yRefPos.append(y)
            else:
                outputList.append(0)
                xRefNeg.append(x)
                yRefNeg.append(y)

            outputMatrix.append(outputList)
            hOne1.append(hO1)
            hOne2.append(hO2)
            hOne3.append(hO3)
            hTwo1.append(hT1)
            hTwo2.append(hT2)
            hTwo3.append(hT3)

        # plot output prediction
        ax2.cla()
        ax2.plot(xRefPos, yRefPos, 'g+', xRefNeg, yRefNeg, 'ro', markersize=20)
        plt.pause(0.1)

        # display data on LED matrices
        sendMatrix(hOne1, 1, 2)
        sendMatrix(hOne2, 1, 3)
        sendMatrix(hOne3, 1, 4)
        sendMatrix(hTwo1, 2, 2)
        sendMatrix(hTwo2, 2, 3)
        sendMatrix(hTwo3, 2, 4)


if __name__ == '__main__':
    functionList = {
        0: 'y >= 0',
        1: 'x >= 0',
        2: 'checkerboard',
        3: 'circle',
        4: 'diagonal',
        5: 'chess',
        6: 'corners',
        7: 'kite'
    }

    print("FUNCTION LIST:")
    for x in range(8):
        print(str(x)+".", functionList[x])

    num = min(int(input("What function would you like to train with? ")), 7)

    # creating input data
    inputData, outputData, refFunc = generateData(numTrain, num)

    # set up model
    model = setupNN(inputData, outputData, numFeatures, numHiddenUnits1, numHiddenUnits2)

    # set up plotting
    plt.ion() # interactive plotting

    # Reference solution
    xRefPos = []
    xRefNeg = []
    yRefPos = []
    yRefNeg = []

    # REF FUNCTION
    for x in range(-4, 4):
        for y in range(-4, 4):
            if refFunc(x, y):
                xRefPos.append(x)
                yRefPos.append(y)
                print('+', end='')
            else:
                xRefNeg.append(x)
                yRefNeg.append(y)
                print('-', end='')
        print()

    xrp = []
    yrp = []
    xrn = []
    yrn = []

    for x in range(len(inputData)):
        tempX = int(inputData[x][0])
        tempY = int(inputData[x][1])

        if outputData[x][0] > 0:
            xrp.append(tempX)
            yrp.append(tempY)
        else:
            xrn.append(tempX)
            yrn.append(tempY)

    # reference solution
    global f, ax1, ax2

    f,(ax1, ax3, ax2) = plt.subplots(1, 3)
    ax1.set_xlim([-5, 4])
    ax1.set_ylim([-5, 4])
    ax2.set_xlim([-5, 4])
    ax2.set_ylim([-5, 4])
    ax3.set_xlim([-5, 4])
    ax3.set_ylim([-5, 4])
    ax1.plot(xRefPos, yRefPos, 'g+', xRefNeg, yRefNeg, 'ro', markersize=20)
    ax3.plot(xrp, yrp, 'g+', xrn, yrn, 'ro', markersize=20)

    # train model
    trainNN(model, numEpochs)

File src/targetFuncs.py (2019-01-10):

'''
Library of target functions to use for NN

Since we are only dealing with binary data, we require that
all functions return either True or False for 1, 0 respectively
'''

from math import sqrt

# circle radius
r = 3

def yGeZero(x, y):
  return y > 0

def xGeZero(x, y):
  return x > 0

def checkerboard(x, y):
  return ((x >= 0) and (y >= 0)) or ((x <= 0) and (y <= 0))

def circle(x, y):
  return sqrt(x*x + y*y) <= r

def diag(x, y):
  return (int(x) == int(y)) or (int(x) == int(y+1)) or (int(x) == int(y-1))

def chess(x, y):
  return (int(x) % 2 != 0) and (int(y) % 2 != 0)

def line(x, y):
  return x == y

def corners(x, y):
  return (x >= 2 and y >= 2) or (x >= 2 and y <= -3) or (x <= -3 and y >= 2) or (x <= -3 and y <= -3)

def kite(x, y):
  return ((abs(y) >= abs(x)) or (y <= -abs(x)))

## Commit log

2018-03-31 python 3 print style
2018-03-31 fixed rest of prints, more useful comments
2018-04-01 impllemented basic matrix driver
2018-04-01 fixed bug with address offset
    [testMatrix.ino]
2018-04-03 CAD files (Solidworks)
    [LEDbackpack.SLDPRT, base.SLDPRT, basesupport.SLDPRT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]
2018-04-03 CAD Files folder
2018-04-03 move to cad files folder
    [LEDbackpack.SLDPRT]
2018-12-29 wiring diagrams
2018-12-30 updated figures with wiring diagrams
    overall wiring for fig3
    corrected wiring fig2
2018-12-30 powerpoint for figures and exploded cad images
2019-01-10 do not commit led backpack library
2019-03-14 support for 6 matrices on an Arduino Mega
